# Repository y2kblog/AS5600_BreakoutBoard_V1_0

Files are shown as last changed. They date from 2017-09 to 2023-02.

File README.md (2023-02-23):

# 12bit (4096P/R) 磁気式エンコーダAS5600 Breakout Board

[English page](https://products.y2kb.com/en/as5600/latest/)

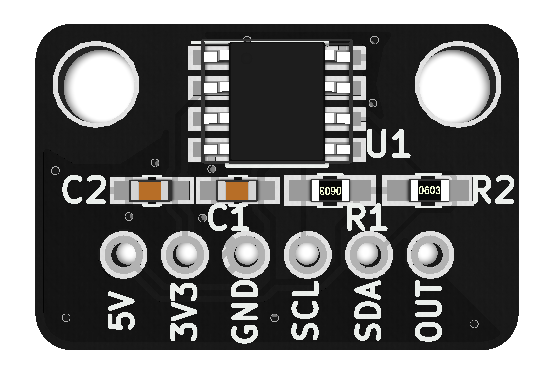
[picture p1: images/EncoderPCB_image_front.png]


## 概要

12bit (4096P/R) 分解能の磁気式アブソリュートエンコーダ AS5600 (ams AG製) を2.54mmピッチに変換する基板です。ネオジム磁石を同梱。  
5V、3.3V、GNDの電源ピンとI2C、アナログ/PWM出力のピンが出ています。電源電圧は5Vもしくは3.3Vです。  
**※AS5601との違いはAS5601の出力方式がA/B相のインクリメンタル出力であるのに対し、AS5600はアナログ/PWM出力である点です。**  

※本ボードは[DCモータ制御シールドV1.0](https://github.com/y2kblog/DCMotorControlShieldV1_0)にも使用しています。

### AS5600の特徴
- 4096P/R の高分解能
- 磁気式のため非接触で角度計測が可能であり、信頼性と耐久性に優れている
- インターフェイス：I2C、アナログ出力もしくはPWM出力
- アナログ出力：角度に対応したアナログ電圧値を出力
- PWM出力：角度に対応したデューティ比のPWM信号を出力
- I2C：設定レジスタにアクセスでき、角度の読み取りや動作設定が可能
- サンプリング時間：150μs
- AS5600とネオジム磁石の中心が1mm程度ずれても値の読み取りが可能

### 基板仕様
- 基板サイズ：横20mm×縦13.5ｍｍ
- 基板マウント用穴：15mmピッチ、M3×2穴
- 電源電圧に5Vを供給する場合は3.3Vピンをオープンに、3.3Vを供給する場合は5Vピンにも3.3Vを供給してください。
- DIRピンはGNDに接続、PGOピンは非接続

## 販売  
[スイッチサイエンス委託販売ページ](https://www.switch-science.com/catalog/3493/)  
※大量注文や在庫に関する問い合わせは[こちら](mailto:info.y2kb@gmail.com)までご連絡ください。  

## 内容物
- AS5600 Breakout Board 本体
- エンコーダ用ネオジム磁石

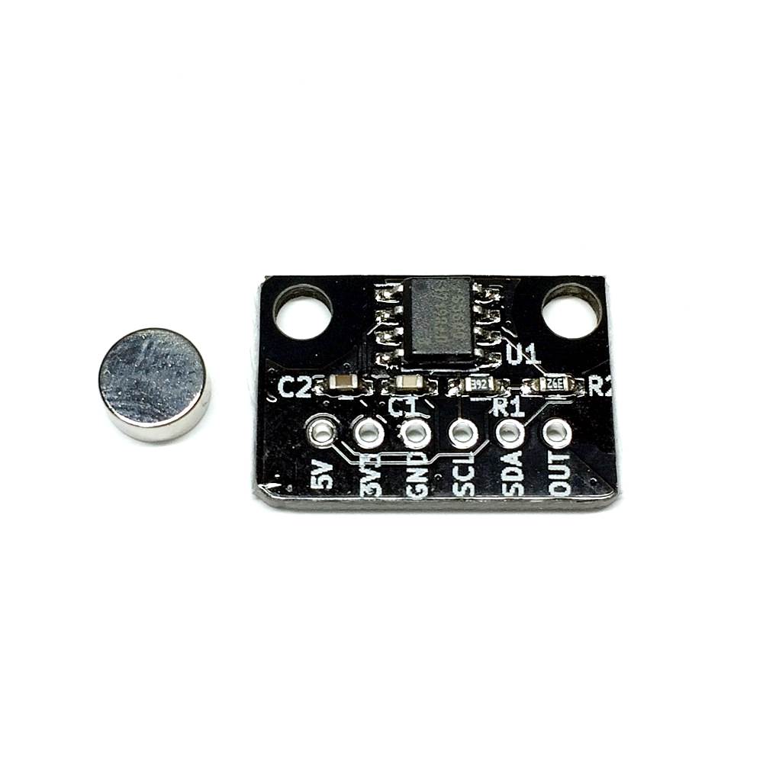
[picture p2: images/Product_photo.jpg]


### 回路図  
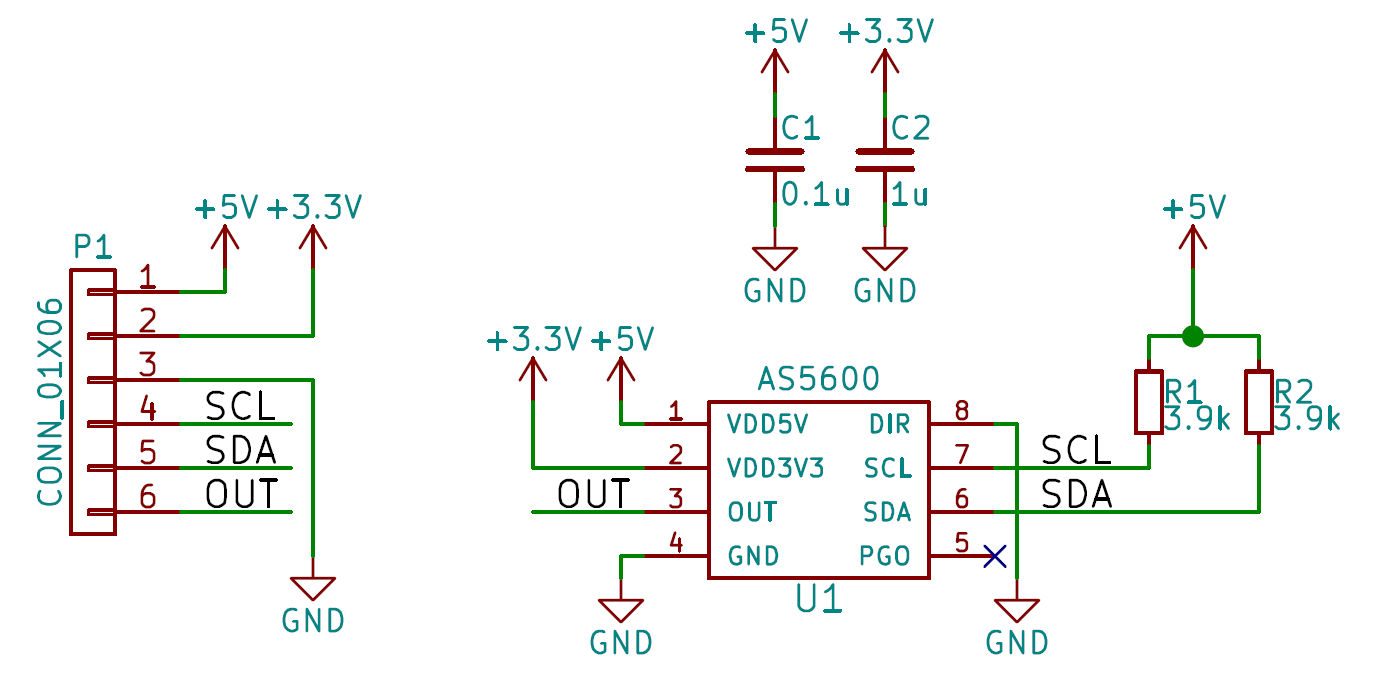
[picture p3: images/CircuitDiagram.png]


### 寸法  
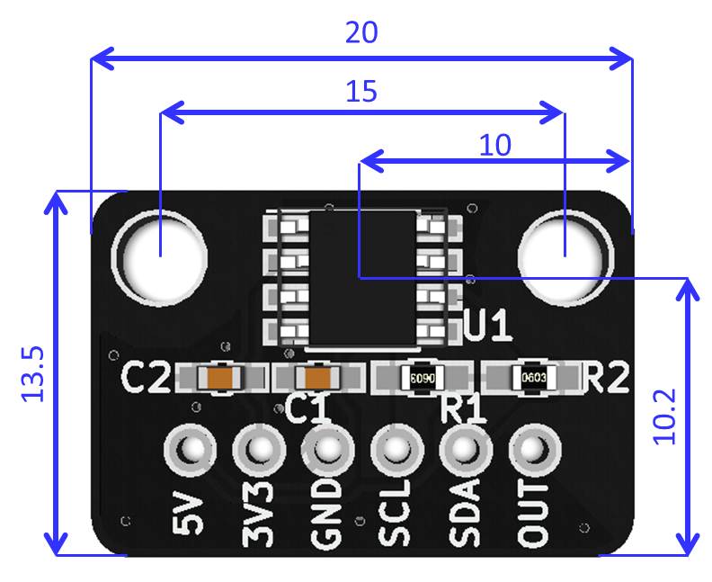
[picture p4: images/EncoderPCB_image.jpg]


## 取付方法
1. 同梱のネオジム磁石を回転体の軸中心に取り付けます
2. AS5600の中心とネオジム磁石の中心が合うよう基板を固定部に取り付けます

**取付例**  
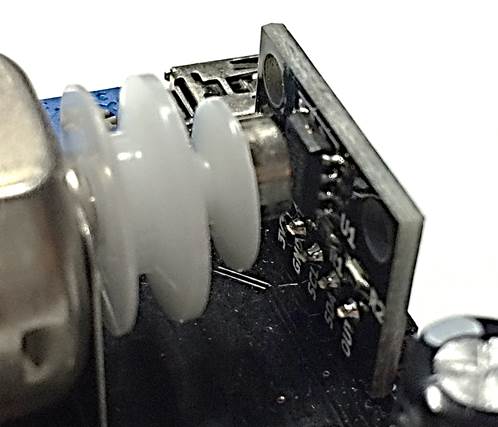
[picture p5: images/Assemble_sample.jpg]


## Arduinoによるプログラム例  

### I2Cによる角度の取得  
#### 配線図  
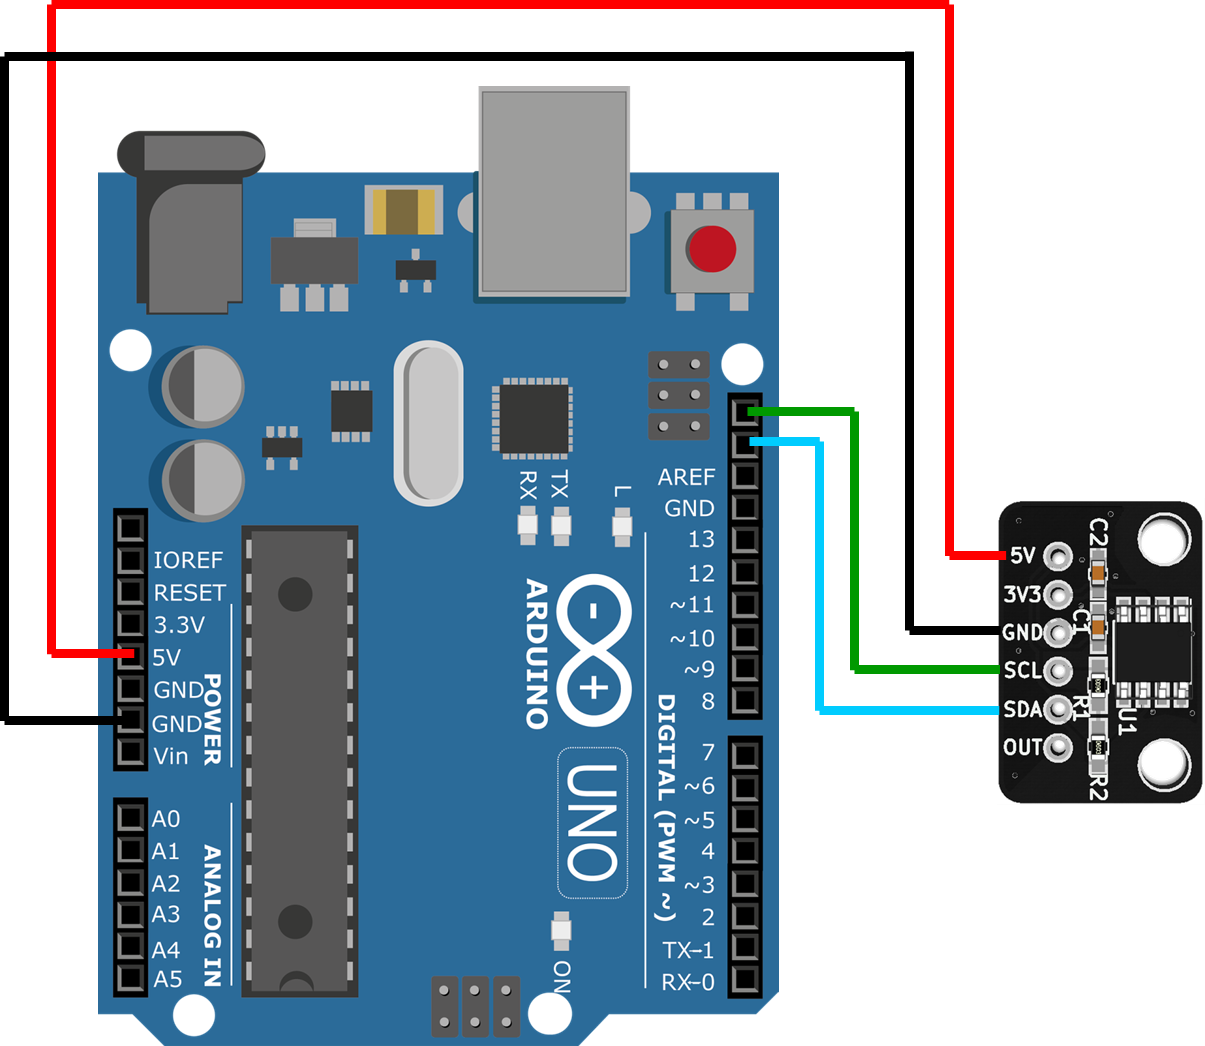
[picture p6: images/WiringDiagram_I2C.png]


#### [ソースファイル](https://github.com/y2kblog/AS5600_BreakoutBoard_V1_0/blob/master/SampleCode/Arduino/I2C_SampleCode/I2C_SampleCode.ino)

<!--
#### ソースファイルのディレクトリ  
"SampleCode/Arduino/I2C_SampleCode/I2C_SampleCode.ino"
-->

#### ミニマムコード  

```cpp
#include <stdint.h>
#include <Wire.h>
#define AS5600_AS5601_DEV_ADDRESS      0x36
#define AS5600_AS5601_REG_RAW_ANGLE    0x0C

void setup() {
  // I2C init
  Wire.begin();
  Wire.setClock(400000);

  // Read RAW_ANGLE value from encoder
  Wire.beginTransmission(AS5600_AS5601_DEV_ADDRESS);
  Wire.write(AS5600_AS5601_REG_RAW_ANGLE);
  Wire.endTransmission(false);
  Wire.requestFrom(AS5600_AS5601_DEV_ADDRESS, 2);
  uint16_t RawAngle = 0;
  RawAngle  = ((uint16_t)Wire.read() << 8) & 0x0F00;
  RawAngle |= (uint16_t)Wire.read();
  // Raw angle value (0 ~ 4095) is stored in RawAngle
}

void loop() {
}
```

### アナログピンを用いた角度の取得  
#### 配線図  
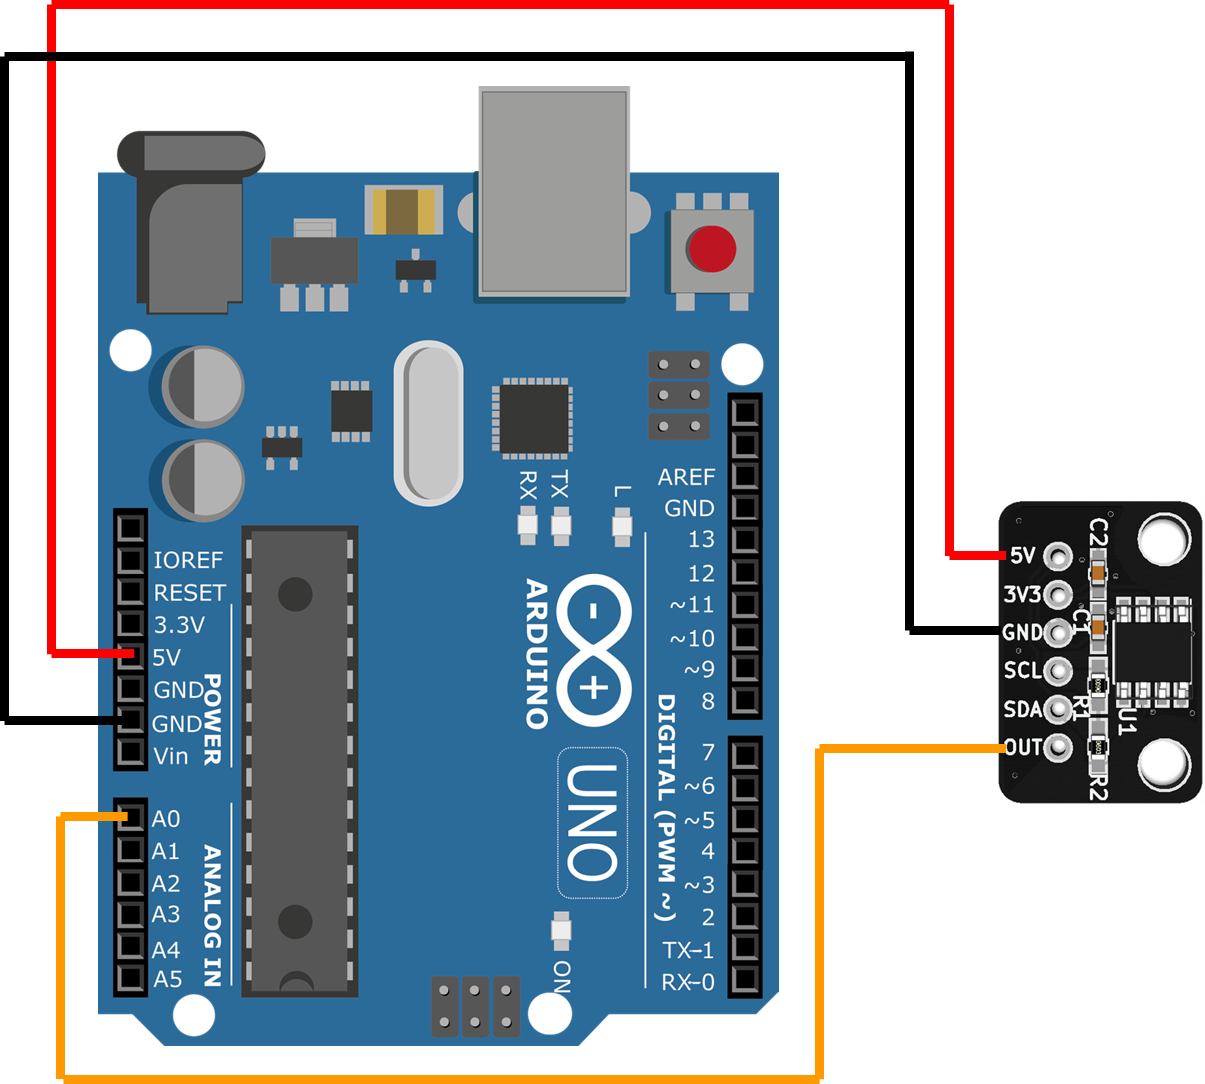
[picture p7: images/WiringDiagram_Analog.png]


#### [ソースファイル](https://github.com/y2kblog/AS5600_BreakoutBoard_V1_0/blob/master/SampleCode/Arduino/Analog_SampleCode/Analog_SampleCode.ino)

<!--
#### ソースファイルのディレクトリ  
"SampleCode/Arduino/I2C_SampleCode/Analog_SampleCode.ino"
-->

#### ミニマムコード  

```cpp
#include <stdint.h>

void setup() {
  uint16_t AnalogValue = 0;
  AnalogValue = analogRead(0);
  AnalogValue &= 0x03FF;
  AnalogValue = 0x03FF - AnalogValue;
  // Angle value (0 ~ 1023) is stored in AnalogValue
}

void loop() {
}
```

<!--
#### STM32 (HAL)

**サンプルコード**
```c
// I2Cの初期化は終わっているとする

#define AS5600_AS5601_DEV_ADDRESS      (0x36<<1)
#define AS5600_AS5601_REG_RAW_ANGLE    0x0C

uint8_t buf[2];
HAL_I2C_Mem_Read(&hi2c, AS5600_AS5601_DEV_ADDRESS,
  AS5600_AS5601_REG_RAW_ANGLE, I2C_MEMADD_SIZE_8BIT,
  (uint8_t*)buf, 2, 1000);
uint16_t RawAngle;
RawAngle = (uint16_t) buf[0] << 8 | (uint16_t) buf[1];
RawAngle &= 0x0FFF;
// Raw angle value (0x0000~0x0FFF) is stored in RawAngle
```
-->

## 資料

- 2Dデータ(DXF)：<a href="https://github.com/y2kblog/AS5600_BreakoutBoard_V1_0/raw/master/PCB_source/dxf/AS5600_BreakoutBoard_V1_0_dxf.zip" download="">AS5600_BreakoutBoard_V1_0_dxf.zip</a>  
- 3Dデータ(STEP)：<a href="https://github.com/y2kblog/AS5600_BreakoutBoard_V1_0/raw/master/PCB_source/step/AS5600_BreakoutBoard_V1_0_step.zip" download="">AS5600_BreakoutBoard_V1_0_step.zip</a>  

## License
MIT License

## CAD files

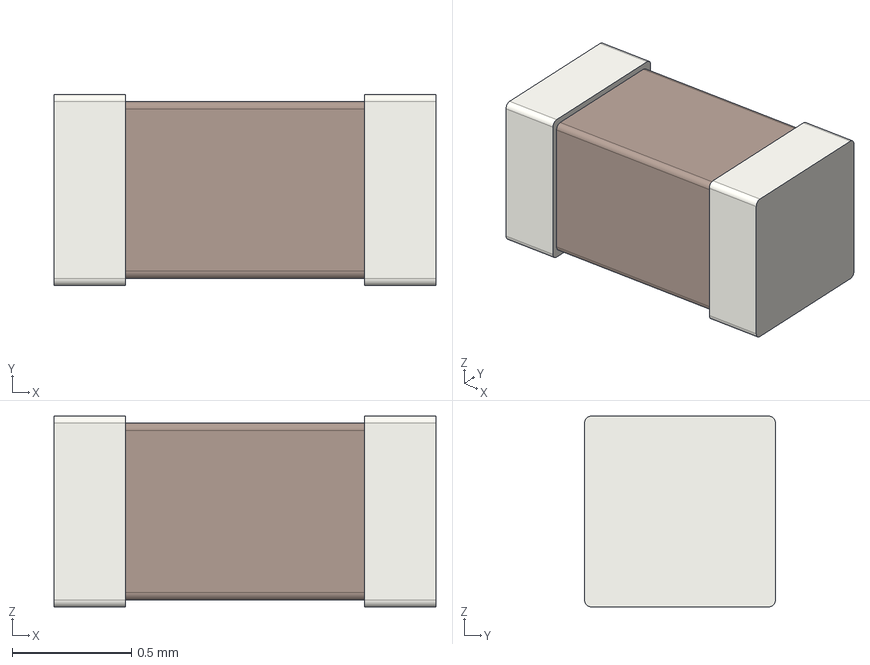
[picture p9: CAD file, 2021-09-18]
PCB_source/3d/C_0603_1608Metric.step
1.60 x 0.8 x 0.8 mm

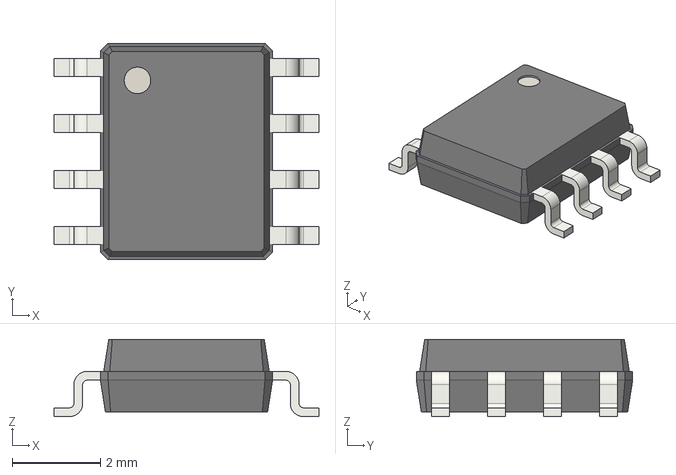
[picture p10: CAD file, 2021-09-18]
PCB_source/3d/SOIC-8_3.9x4.9mm_P1.27mm.step
6.00 x 4.90 x 1.75 mm

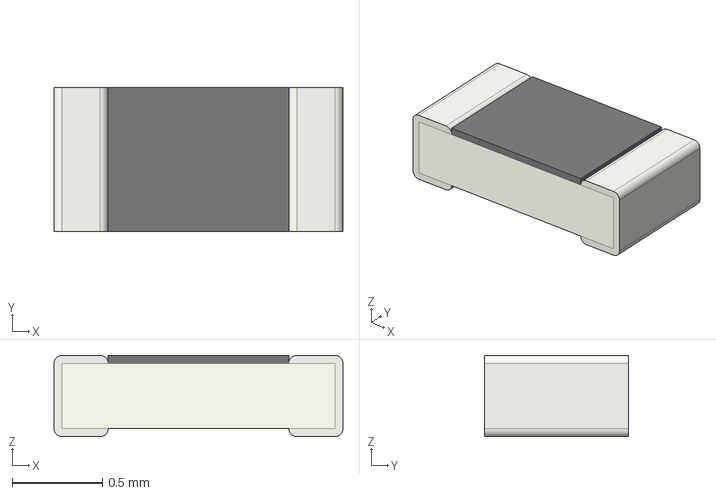
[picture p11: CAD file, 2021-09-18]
PCB_source/3d/R_0603_1608Metric.step
1.60 x 0.8 x 0.45 mm

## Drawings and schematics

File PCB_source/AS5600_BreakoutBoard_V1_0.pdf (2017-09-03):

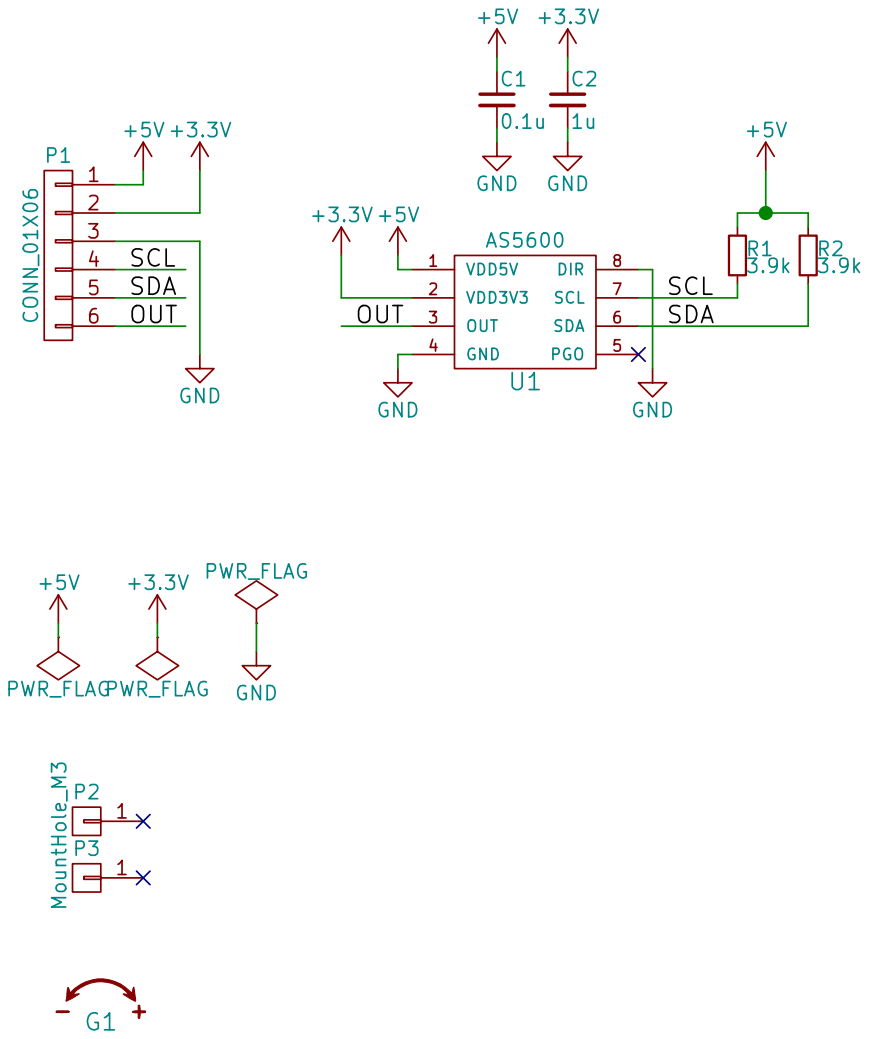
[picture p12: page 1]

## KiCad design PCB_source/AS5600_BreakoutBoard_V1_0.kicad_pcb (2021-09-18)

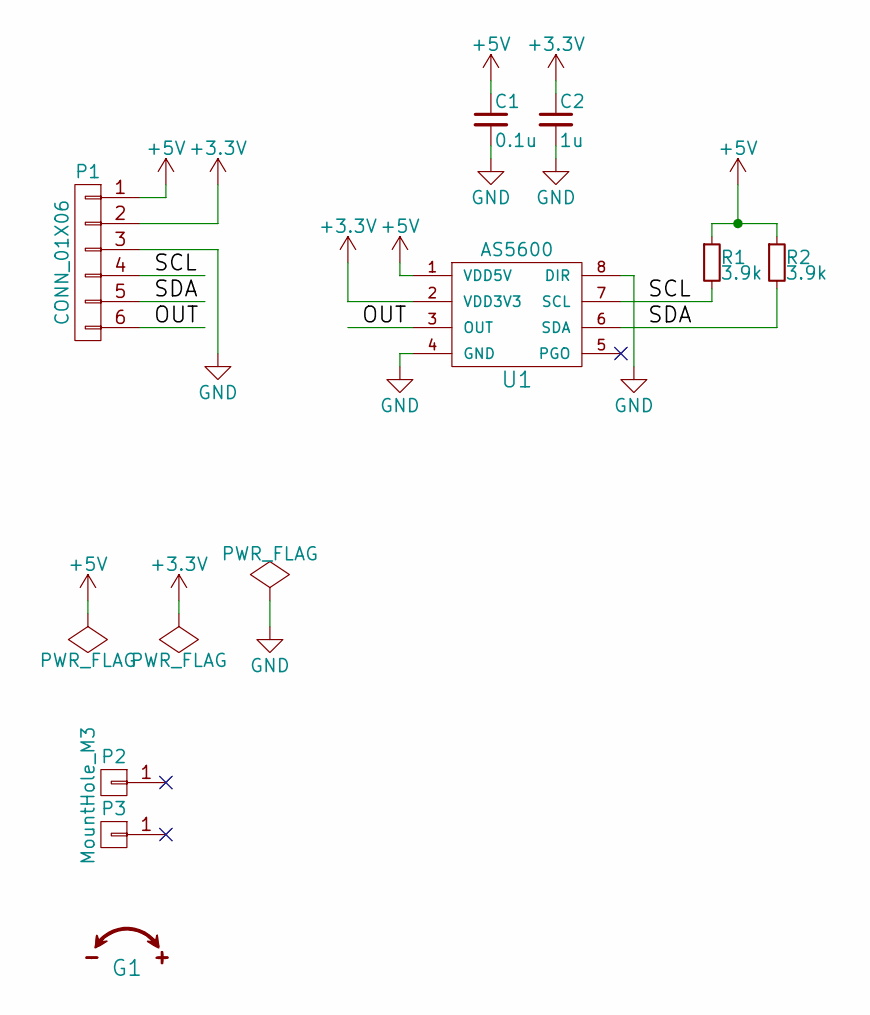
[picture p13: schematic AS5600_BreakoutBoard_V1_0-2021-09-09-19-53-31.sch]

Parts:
C1: 0.1u; C_0603_HandSoldering
C2: 1u; C_0603_HandSoldering
G1: LOGO; Logo_DirRot_v01
P1: CONN_01X06; USER_SIL-6
P2, P3: MountHole_M3; MountingHole_3.2mm_M3
R1, R2: 3.9k; R_0603_HandSoldering
U1: AS5600; SOIC-8_3.9x4.9mm_Pitch1.27mm

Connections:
+3V3: C2.1, P1.2, U1.2 (VDD3V3)
+5V: C1.1, P1.1, R1.1, R2.1, U1.1 (VDD5V)
/OUT: P1.6, U1.3 (OUT)
/SCL: P1.4, R1.2, U1.7 (SCL)
/SDA: P1.5, R2.2, U1.6 (SDA)
GND: C1.2, C2.2, P1.3, U1.4 (GND), U1.8 (DIR)


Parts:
C1: 0.1u; C_0603_HandSoldering
C2: 1u; C_0603_HandSoldering
G1: LOGO; Logo_DirRot_v01
P1: CONN_01X06; USER_SIL-6
P2, P3: MountHole_M3; MountingHole_3.2mm_M3
R1, R2: 3.9k; R_0603_HandSoldering
U1: AS5600; SOIC-8_3.9x4.9mm_Pitch1.27mm

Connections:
+3V3: C2.1, P1.2, U1.2 (VDD3V3)
+5V: C1.1, P1.1, R1.1, R2.1, U1.1 (VDD5V)
/OUT: P1.6, U1.3 (OUT)
/SCL: P1.4, R1.2, U1.7 (SCL)
/SDA: P1.5, R2.2, U1.6 (SDA)
GND: C1.2, C2.2, P1.3, U1.4 (GND), U1.8 (DIR)

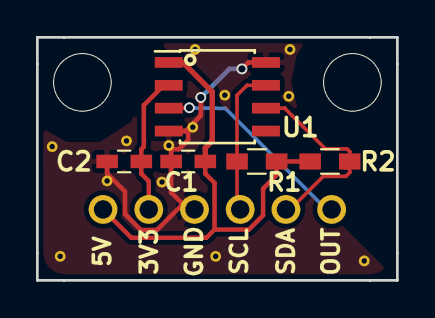
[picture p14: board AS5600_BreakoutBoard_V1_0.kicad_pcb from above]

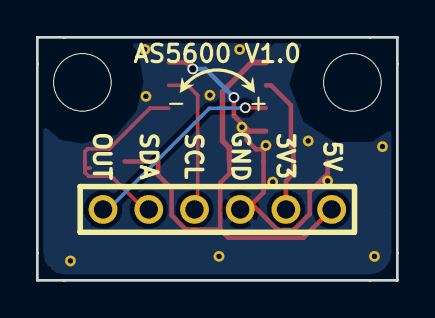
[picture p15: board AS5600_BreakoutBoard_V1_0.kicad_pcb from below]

Board: 2 copper layers, 20.0 x 13.5 mm, 9 parts (2 on the bottom side), 6 nets.

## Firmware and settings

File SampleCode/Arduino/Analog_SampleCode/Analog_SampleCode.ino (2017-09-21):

/* ----- Pin setting -----
   PC0 - Analog   0 - Encoder OUT
*/

#include <stdint.h>

void setup() {
  // Communication function init
  Serial.begin(115200);
  while (!Serial);
}

void loop() {
  uint16_t AnalogValue = 0;
  AnalogValue = analogRead(0);
  AnalogValue &= 0x03FF;
  AnalogValue = 0x03FF - AnalogValue;
  // Angle value (0x0000~0x03FF) is stored in AnalogValue
  
  Serial.println(AnalogValue);
  delay(200);
}

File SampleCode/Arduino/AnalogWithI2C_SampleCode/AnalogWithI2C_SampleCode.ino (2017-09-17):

/* ----- Pin setting -----
   PC4 - Analog   4 - Encoder SDA
   PC5 - Analog   5 - Encoder SCL
   PC0 - Analog   0 - Encoder OUT
*/

#include <stdint.h>
#include <Wire.h>
#define AS5600_AS5601_DEV_ADDRESS       0x36
#define AS5600_AS5601_REG_CONF          0x07
#define AS5600_AS5601_REG_STATUS        0x0B

void Encoder_I2C_init(void){
  byte error;
  uint8_t data;

  // Read AS5601 status register
  Wire.beginTransmission(AS5600_AS5601_DEV_ADDRESS);
  Wire.write(AS5600_AS5601_REG_STATUS);
  Wire.endTransmission(false);
  Wire.requestFrom(AS5600_AS5601_DEV_ADDRESS, 1);
  data = Wire.read();
  data &= 0x38;
  if (data != 0x20)
  {
    Serial.print("Magnet error : ");
    if ( !(data & 0x20) )
      Serial.println("Magnet was not detected");
    if (data & 0x10)
      Serial.println("Magnet too weak");
    if (data & 0x08)
      Serial.println("Magnet too strong");
    Serial.println("Stop");
    for(;;);
  }
  else
    Serial.println("Magnet : OK");

  // Write AS5601 conf
  Wire.beginTransmission(AS5600_AS5601_DEV_ADDRESS);
  Wire.write(AS5600_AS5601_REG_CONF);
  Wire.write(0b00000111);   // WD = 0b0, FTH = 0b001, SF = 0b11
  error = Wire.endTransmission();
  if (error)
  {
    Serial.print("error=");
    Serial.println(error);
  }
  delay(1);
}

void setup() {
  // I2C init
  Wire.begin();
  Wire.setClock(400000);

  // Communication function init
  Serial.begin(115200);
  while (!Serial);

  // Peripheral init
  Encoder_I2C_init();
}

void loop() {
  uint16_t AnalogValue = 0;
  AnalogValue = analogRead(0);
  AnalogValue &= 0x03FF;
  AnalogValue = 0x03FF - AnalogValue;
  Serial.println(AnalogValue);
  delay(200);
}

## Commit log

2017-09-07 fix sample code bug
    [Arduino_AS5600_AS5601_SampleCode.ino]
2017-09-17 Add sample code using Analog output
2017-09-22 Add circuit diagram
2021-09-18 add step and refactoring
    [AS5600_BreakoutBoard_V1_0-2021-09-09-19-53-31.sch, AS5600_BreakoutBoard_V1_0-2021-09-18-11-00-43.sch, AS5600_BreakoutBoard_V1_0.dsn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]

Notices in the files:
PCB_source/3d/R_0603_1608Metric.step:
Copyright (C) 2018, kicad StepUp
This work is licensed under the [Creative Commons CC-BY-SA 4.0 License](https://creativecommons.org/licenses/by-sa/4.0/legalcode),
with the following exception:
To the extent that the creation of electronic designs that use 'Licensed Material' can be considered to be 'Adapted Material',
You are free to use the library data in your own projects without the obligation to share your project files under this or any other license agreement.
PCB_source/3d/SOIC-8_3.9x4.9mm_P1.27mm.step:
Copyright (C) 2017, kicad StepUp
